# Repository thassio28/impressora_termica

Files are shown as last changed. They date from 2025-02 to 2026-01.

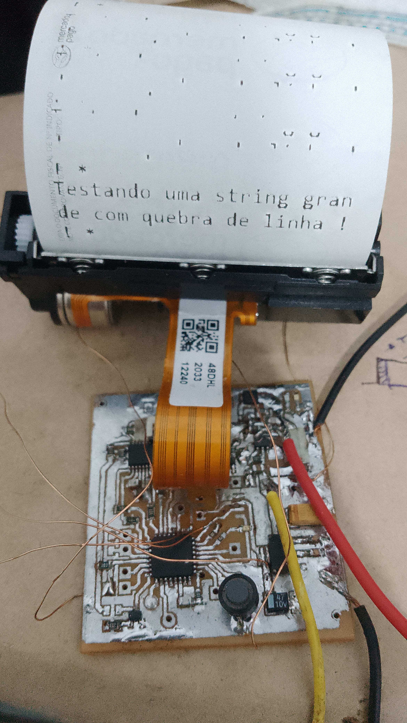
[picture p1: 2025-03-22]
IMG_20240728_152725_571 (1).jpg

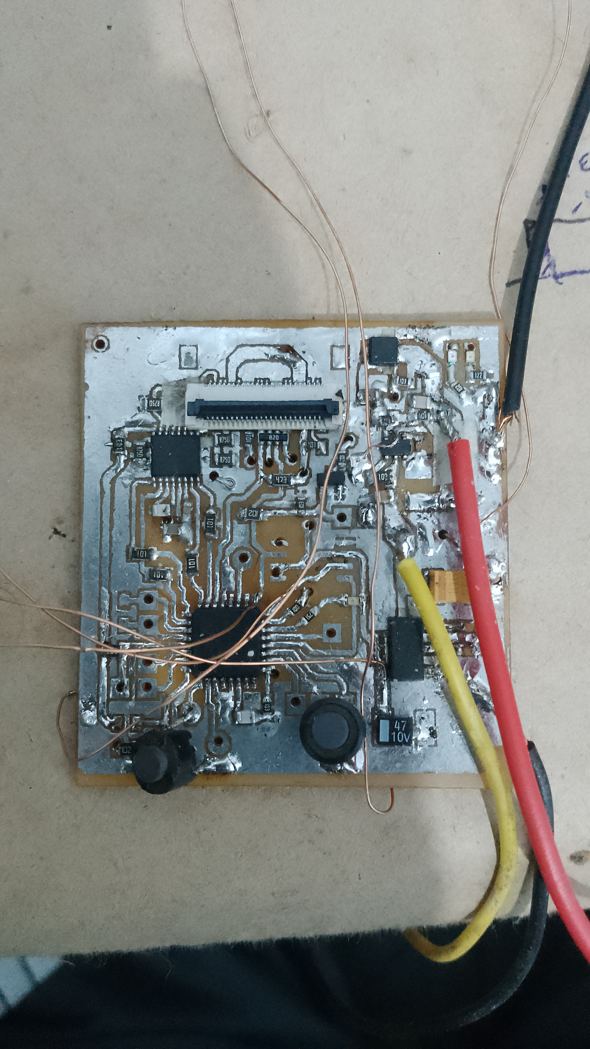
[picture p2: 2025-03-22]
IMG_20240727_220041_866.jpg

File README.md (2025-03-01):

# impressora_termica
Impressora térmica  com atmega328p e cabeça térmica LTP02-245.

Para fazer uma impressão deve ser enviado o texto por meio da porta serial com o comando CR (13) ao final da frase, ao apertar o botão o texto é impresso e é retornado pela serial o texto recebido.

Tensão comunicação 3,3V
BAUD = 9600
Tensão máxima da cabeça térmica (VP) 8V.
Clock interno 8 Mhz

Código e esquema ainda em fase de desenvolvimento.

Versão 1

Video impresão de texto: https://youtube.com/shorts/1QFV2fXhjIA?feature=share

Atualização futura, impressão de imagem: https://youtube.com/shorts/7ARQ239Vu7w?feature=share

Versão 2
Atualização futura 2, talvez display OLED.

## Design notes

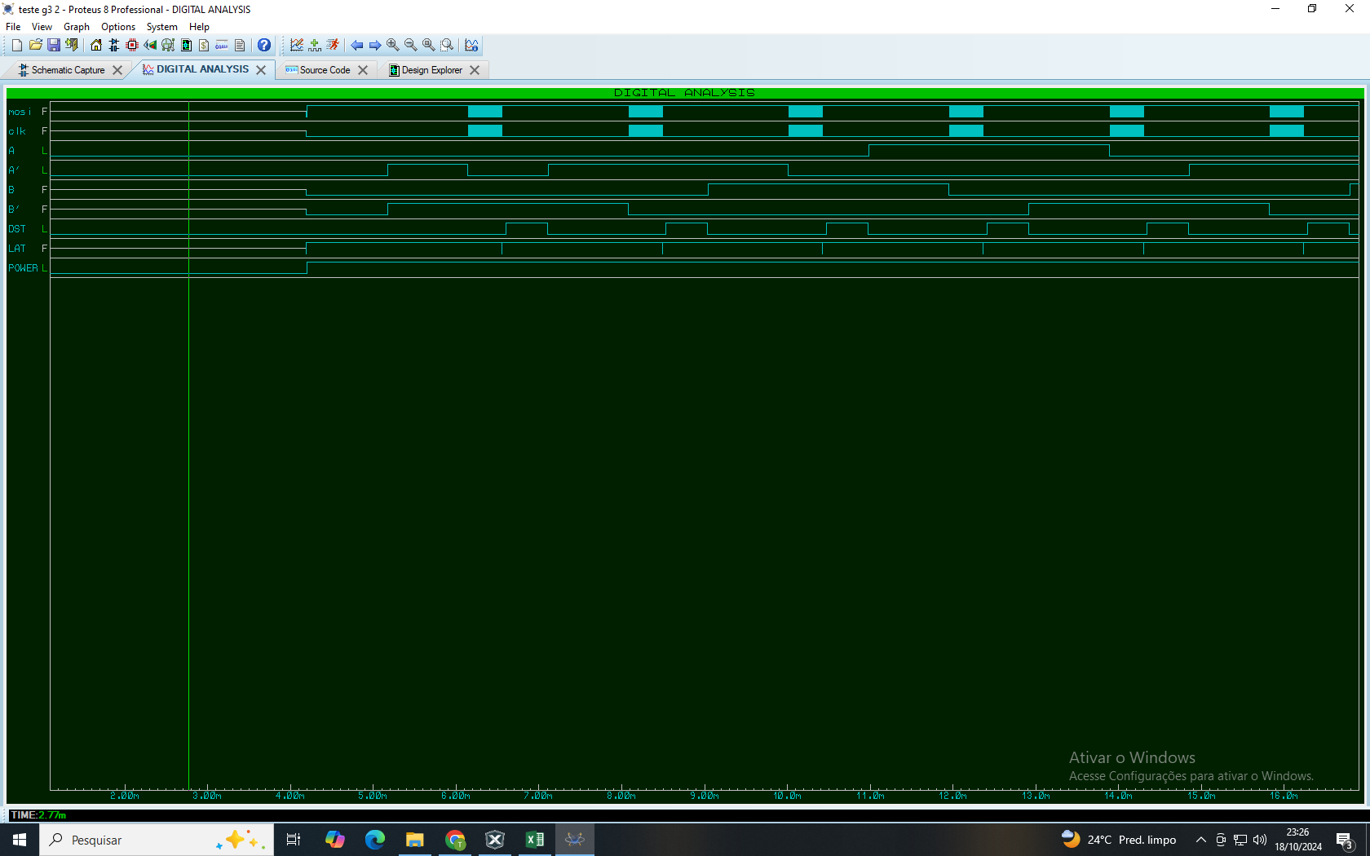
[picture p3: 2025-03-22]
Captura de Tela (138).png

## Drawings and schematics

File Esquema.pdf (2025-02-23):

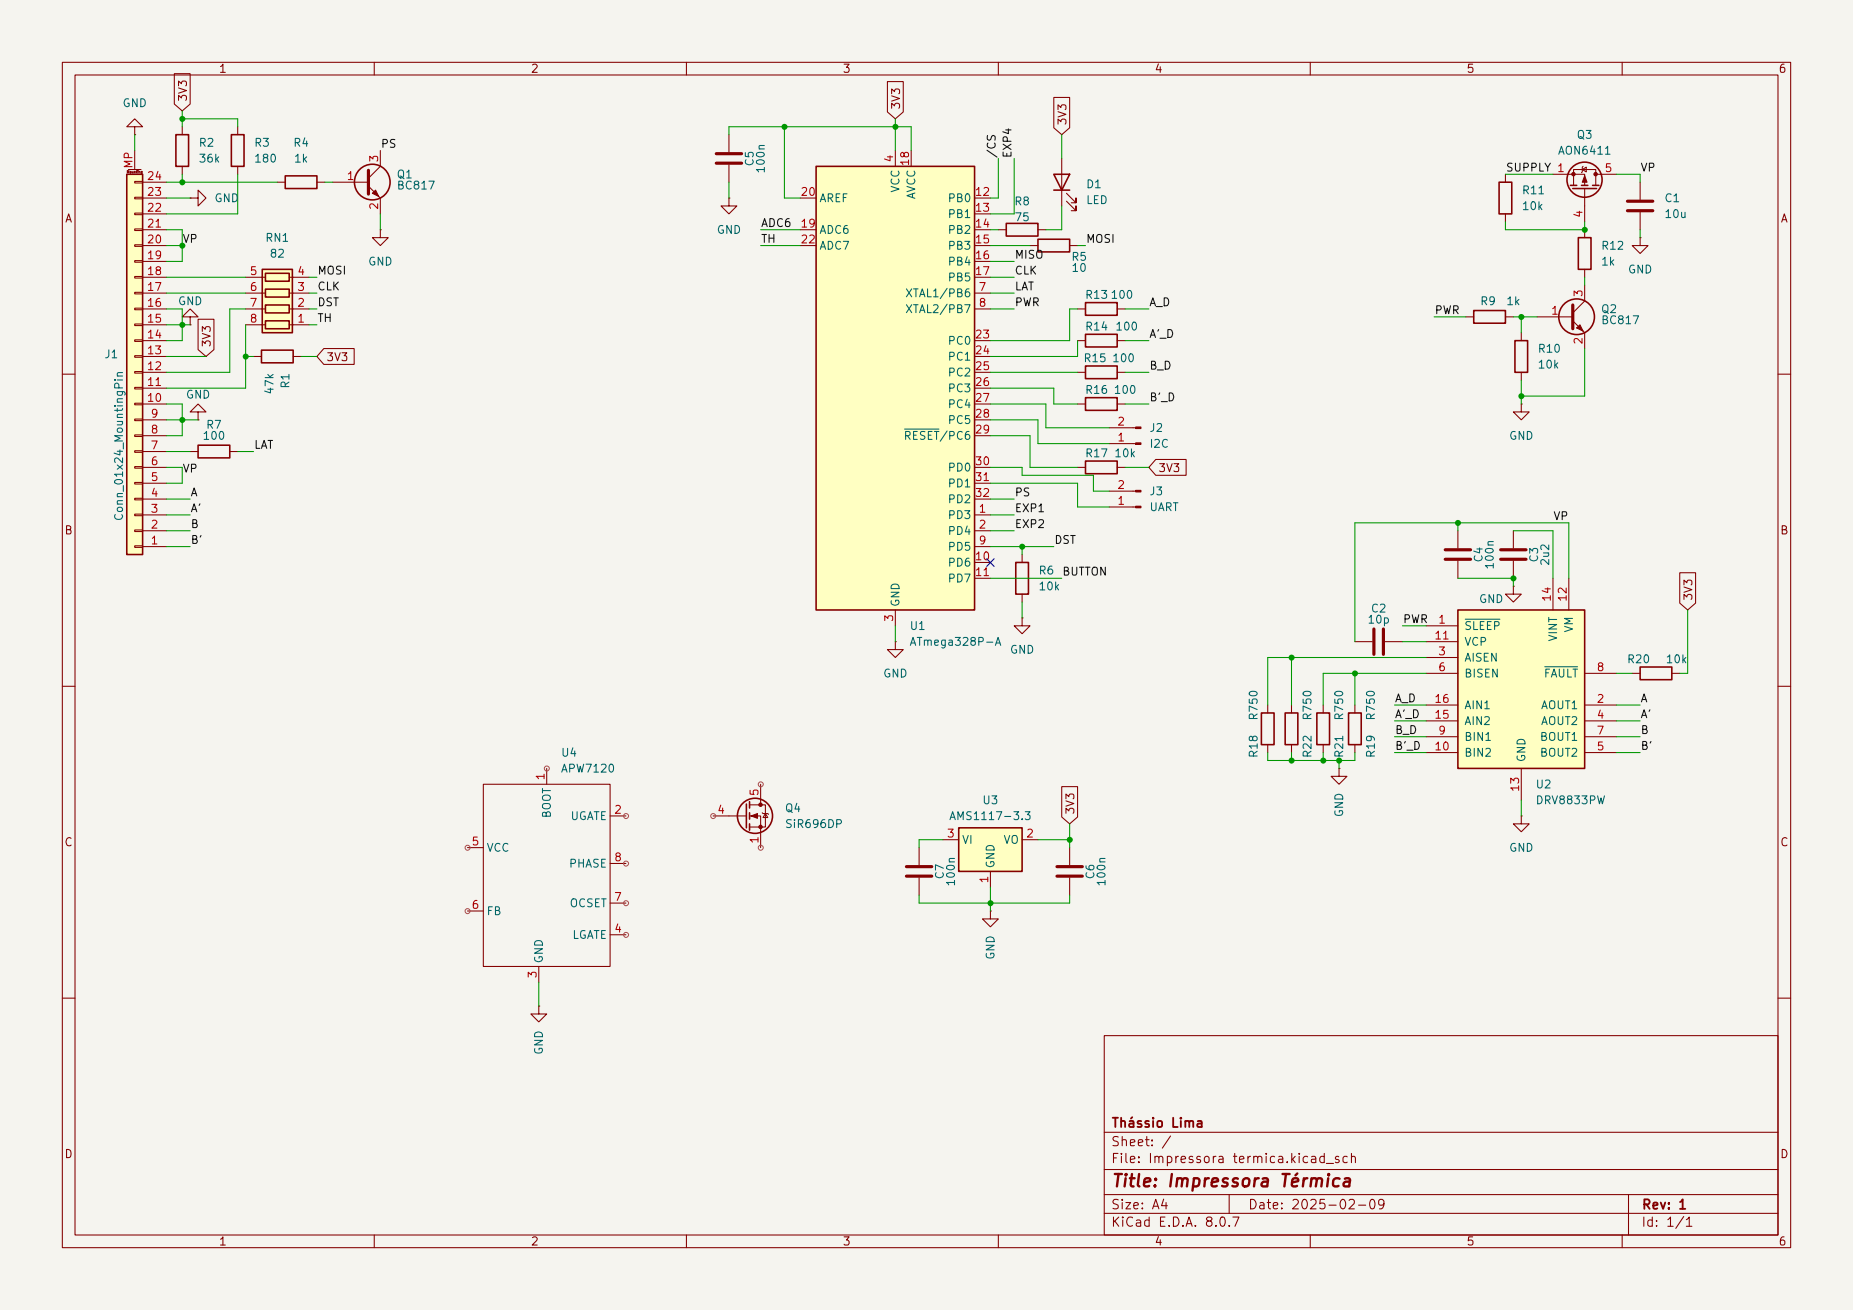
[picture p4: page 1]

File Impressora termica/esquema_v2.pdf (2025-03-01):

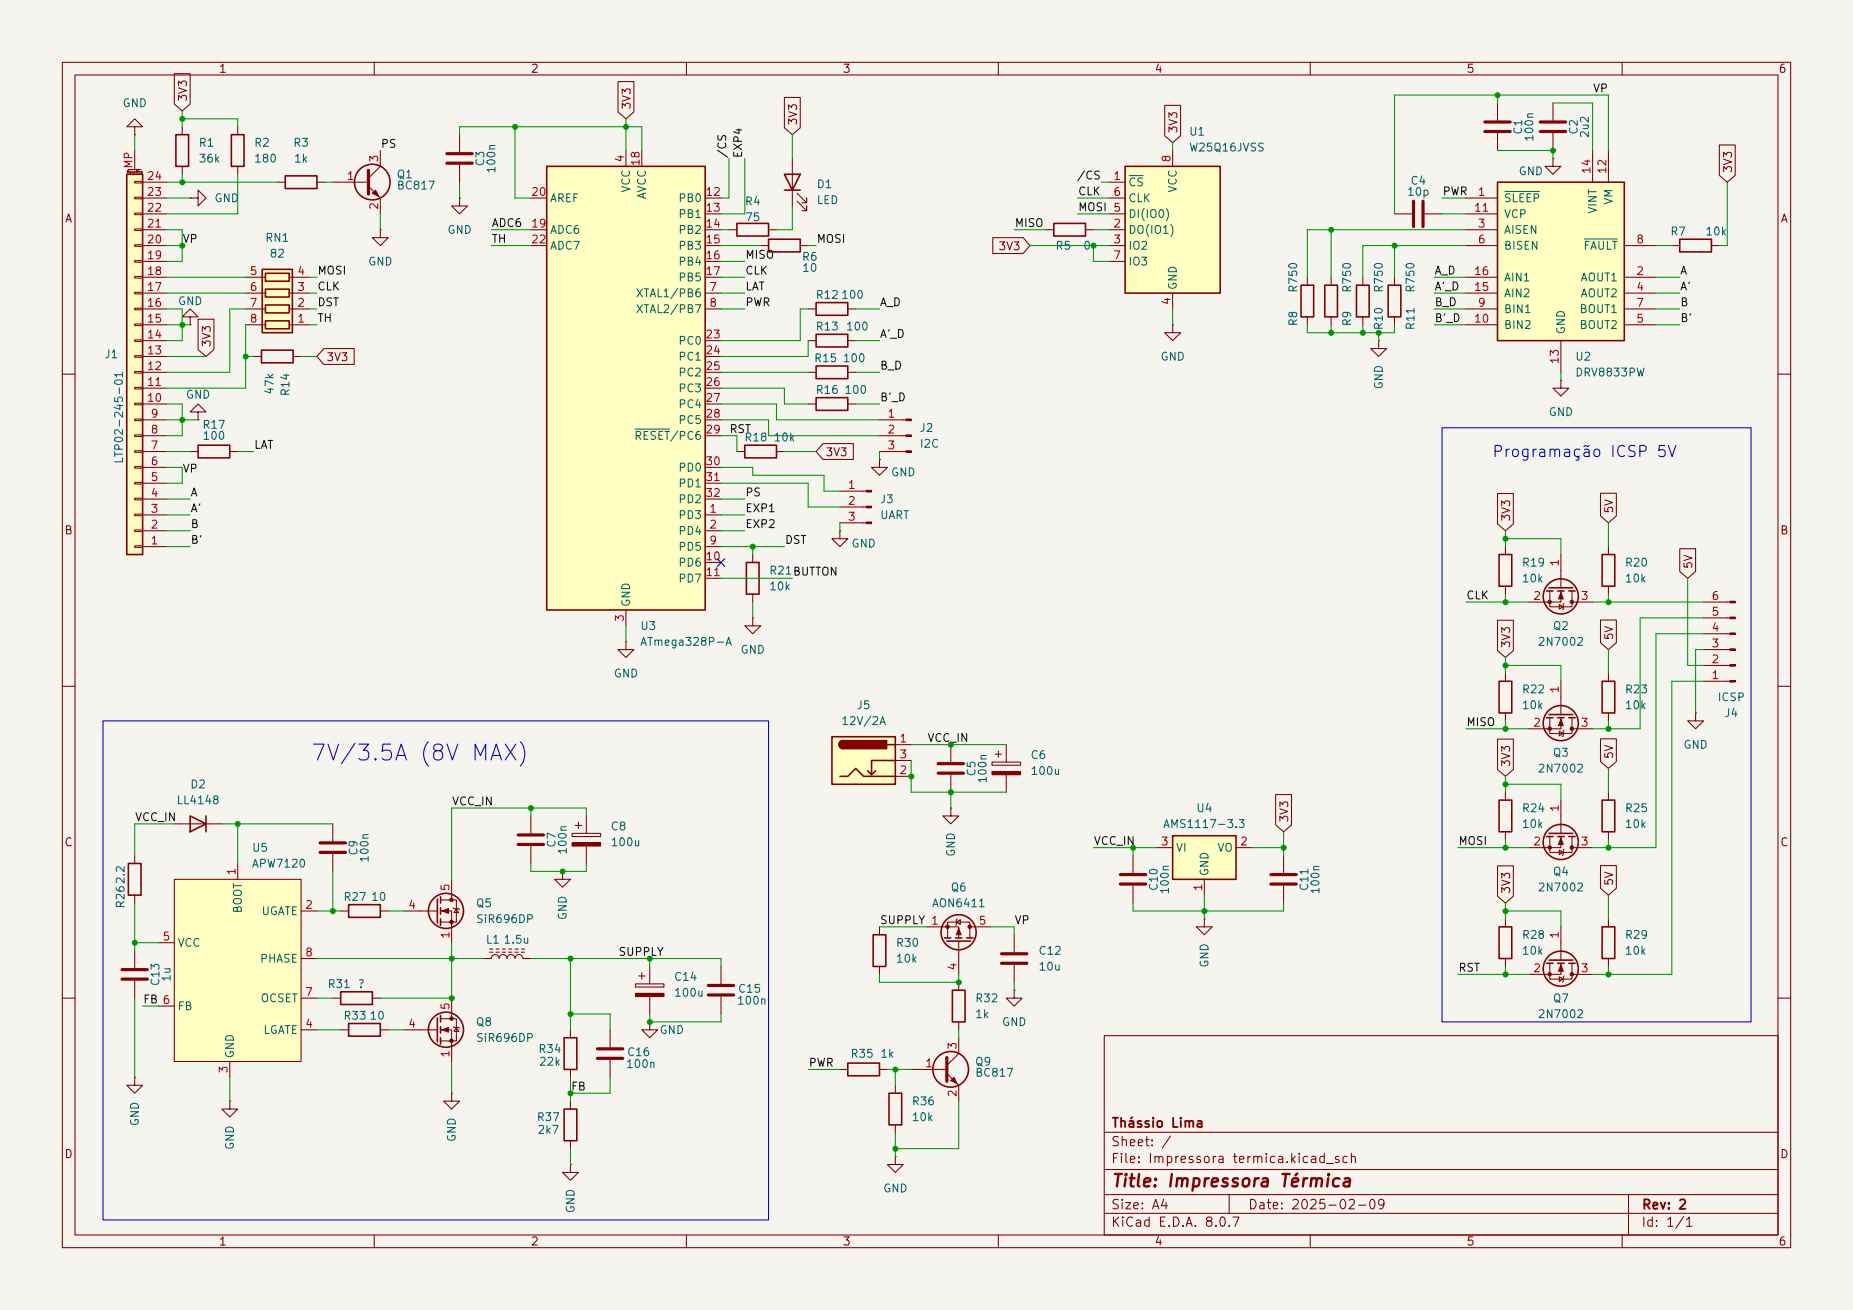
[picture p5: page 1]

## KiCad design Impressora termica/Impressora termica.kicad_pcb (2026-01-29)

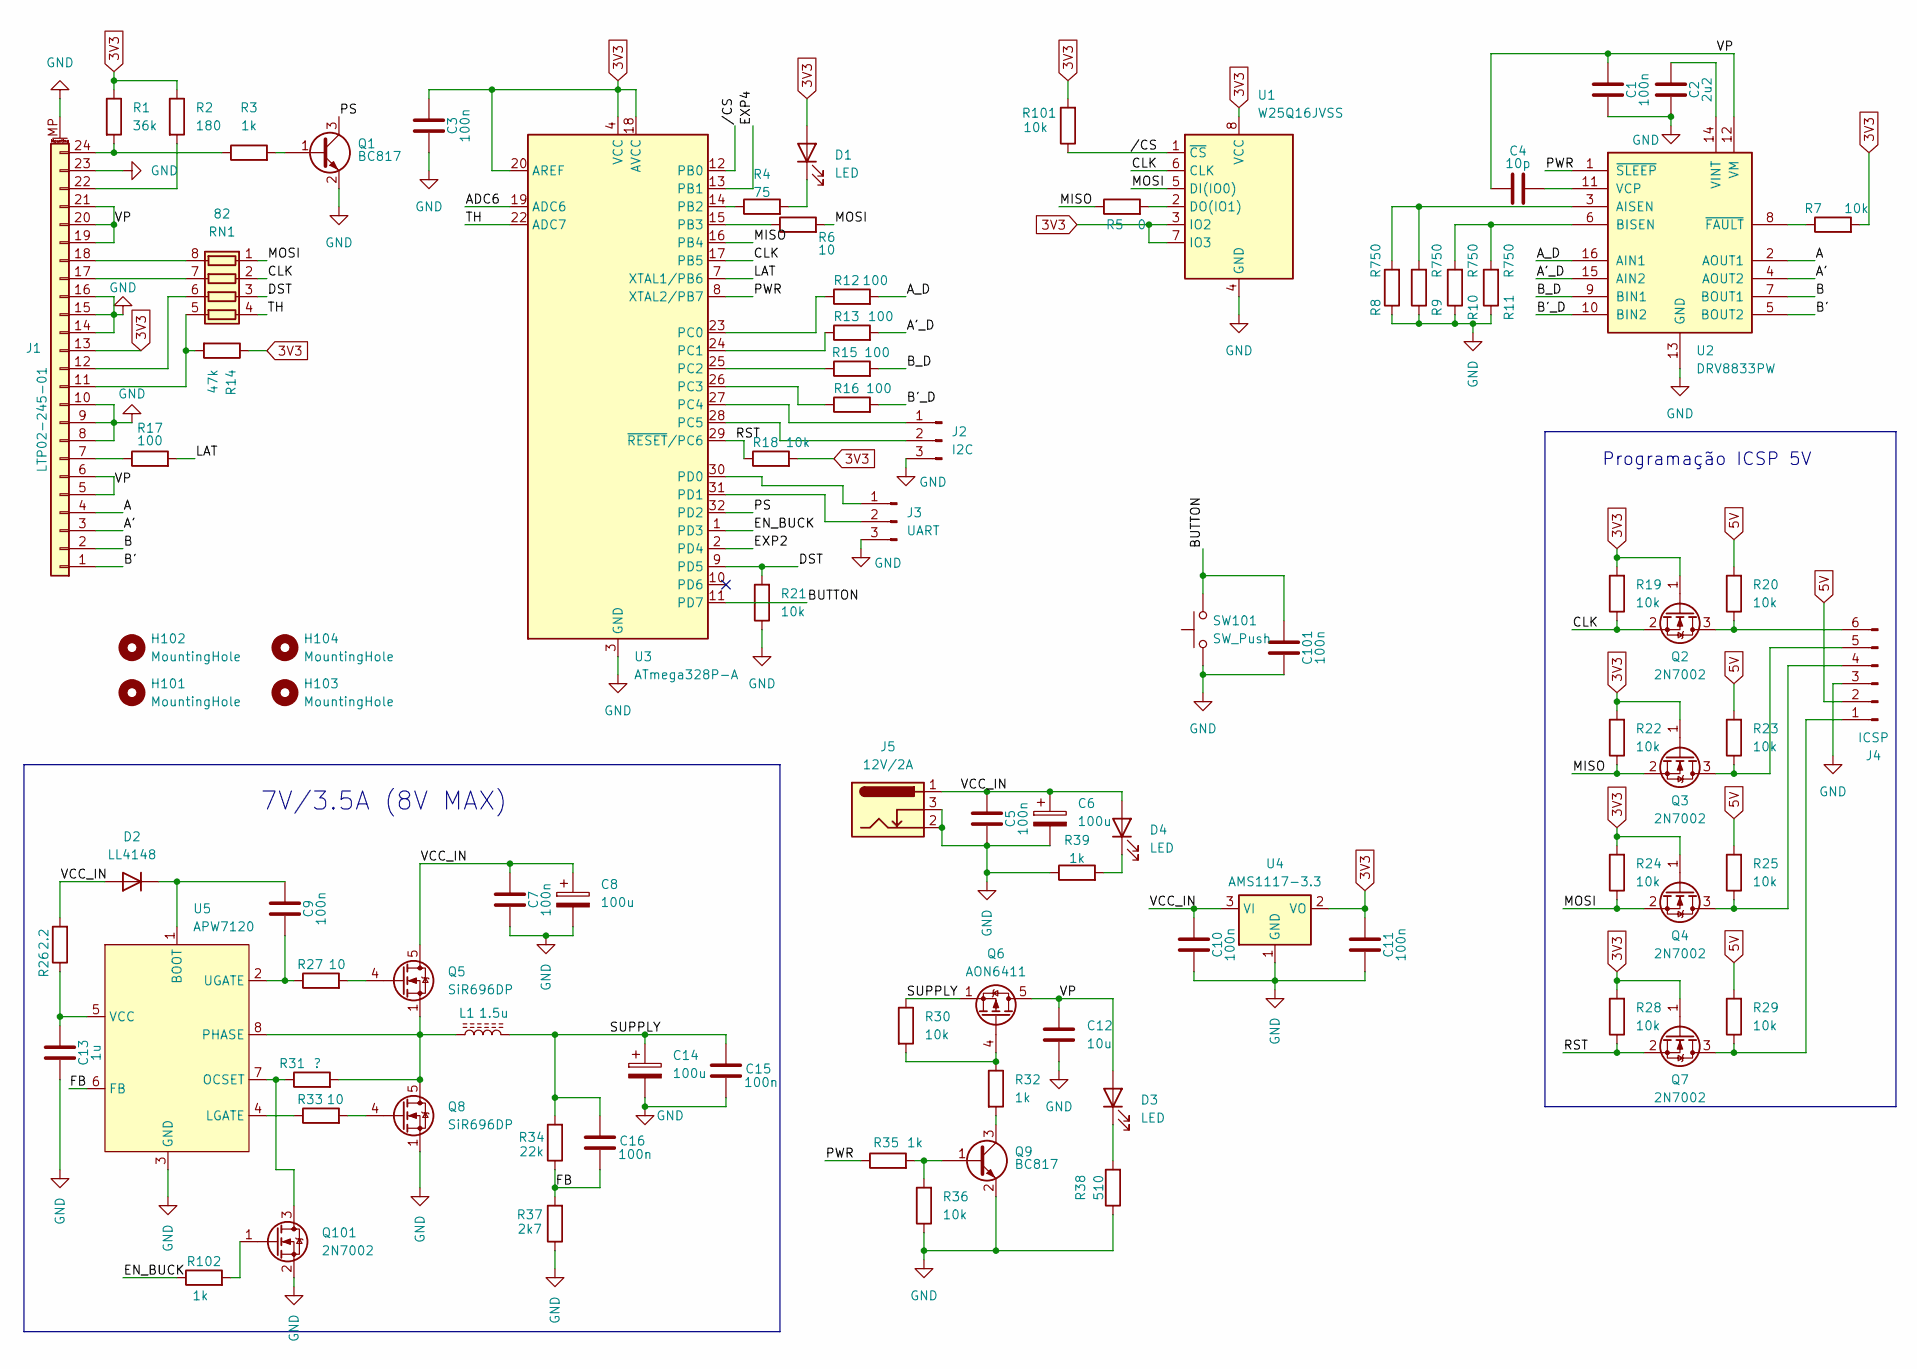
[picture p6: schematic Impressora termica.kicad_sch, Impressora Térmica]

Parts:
C1, C3, C5, C7, C9, C10, C11, C15, C16, C101: 100n; C_0805_2012Metric
C2: 2u2; C_0805_2012Metric
C4: 10p; C_0805_2012Metric
C6: 100u; CP_Elec_6.3x4.5
C8, C14: 100u; CP_Elec_5x4.5
C12: 10u; C_0805_2012Metric
C13: 1u; C_0805_2012Metric
D1, D3, D4: LED; LED_0805_2012Metric
D2: LL4148; D_MiniMELF
H101, H102, H103, H104: MountingHole; MountingHole_3.2mm_M3_DIN965
J1: LTP02-245-01; Hirose_FH12-24S-0.5SH_1x24-1MP_P0.50mm_Horizontal
J2: I2C; PinHeader_1x03_P2.54mm_Vertical
J3: UART; PinHeader_1x03_P2.54mm_Vertical
J4: ICSP; PinHeader_1x06_P2.54mm_Vertical
J5: 12V/2A; BarrelJack_GCT_DCJ200-10-A_Horizontal
L1: 1.5u; L_APV_ANR8040
Q1, Q9: BC817; SOT-23
Q2, Q3, Q4, Q7, Q101: 2N7002; SOT-23
Q5, Q8: SiR696DP; DFN8_3x3_EP_AOS
Q6: AON6411; DFN8_3x3_EP_AOS
R1: 36k; R_0603_1608Metric
R2: 180; R_0603_1608Metric
R3, R35: 1k; R_0805_2012Metric
R4: 75; R_0603_1608Metric
R5: 0; R_0603_1608Metric
R6: 10; R_0805_2012Metric
R7: 10k; R_1206_3216Metric
R8, R9, R10, R11: R750; R_0805_2012Metric
R12, R13, R15, R16: 100; R_0805_2012Metric
R14: 47k; R_0805_2012Metric
R17: 100; R_0603_1608Metric
R18: 10k; R_0805_2012Metric
R19, R20, R21, R22, R23, R24, R25, R28, R29, R30, R36, R101: 10k; R_0603_1608Metric
R26: 2.2; R_0805_2012Metric
R27, R33: 10; R_0603_1608Metric
R31: ?; R_0805_2012Metric
R32, R39, R102: 1k; R_0603_1608Metric
R34: 22k; R_0603_1608Metric
R37: 2k7; R_0603_1608Metric
R38: 510; R_0603_1608Metric
RN1: 82; R_Array_Convex_4x0603
SW101: SW_Push; SW_SPST_CK_RS282G05A3
U1: W25Q16JVSS; SOIC-8_5.23x5.23mm_P1.27mm
U2: DRV8833PW; TSSOP-16_4.4x5mm_P0.65mm
U3: ATmega328P-A; TQFP-32_7x7mm_P0.8mm
U4: AMS1117-3.3; SOT-223-3_TabPin2
U5: APW7120; SOP-8_5.28x5.23mm_P1.27mm

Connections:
3V3: C3.2, C11.2, D1.2 (A), J1.13, Q2.1 (G), Q3.1 (G), Q4.1 (G), Q7.1 (G), R1.1, R2.1, R7.2, R14.1, R18.2, R19.2, R22.2, R24.2, R28.2, R101.2, U1.3 (IO2), U1.7 (IO3), U1.8 (VCC), U3.4 (VCC), U3.6 (VCC), U3.18 (AVCC), U3.20 (AREF), U4.2 (VO)
5V: J4.2, R20.2, R23.2, R25.2, R29.2
/A: J1.4, U2.2 (AOUT1)
/A': J1.3, U2.4 (AOUT2)
/A'_D: R13.2, U2.15 (AIN2)
/ADC6: U3.19 (ADC6)
/A_D: R12.2, U2.16 (AIN1)
/B: J1.2, U2.7 (BOUT1)
/B': J1.1, U2.5 (BOUT2)
/B'_D: R16.2, U2.10 (BIN2)
/BUTTON: C101.2, SW101.2, U3.11 (PD7)
/B_D: R15.2, U2.9 (BIN1)
/CLK: Q2.2 (S), R19.1, RN1.2 (R2.1), U1.6 (CLK), U3.17 (PB5)
/DST: R21.2, RN1.3 (R3.1), U3.9 (PD5)
/EN_BUCK: R102.1, U3.1 (PD3)
/EXP2: U3.2 (PD4)
/EXP4: U3.13 (PB1)
/FB: C16.1, R34.1, R37.2, U5.6 (FB)
/LAT: R17.2, U3.7 (XTAL1/PB6)
/MISO: Q3.2 (S), R5.1, R22.1, U3.16 (PB4)
/MOSI: Q4.2 (S), R6.2, R24.1, RN1.1 (R1.1), U1.5 (DI(IO0))
/PS: Q1.3 (C), U3.32 (PD2)
/PWR: R35.1, U2.1 (~SLEEP), U3.8 (XTAL2/PB7)
/RST: Q7.2 (S), R18.1, R28.1, U3.29 (~RESET/PC6)
/SUPPLY: C14.1, C15.2, C16.2, L1.2, Q6.1 (S), Q6.2 (S), Q6.3 (S), R30.1, R34.2
/TH: RN1.4 (R4.1), U3.22 (ADC7)
/VCC_IN: C5.2, C6.1, C7.2, C8.1, C10.2, D2.2 (A), D4.2 (A), J5.1, Q5.5 (D), R26.2, U4.3 (VI)
/VP: C1.2, C4.1, C12.1, D3.2 (A), J1.5, J1.6, J1.19, J1.20, J1.21, Q6.5 (D), U2.12 (VM)
//CS: R101.1, U1.1 (~CS), U3.12 (PB0)
GND: C1.1, C2.1, C3.1, C5.1, C6.2, C7.1, C8.2, C10.1, C11.1, C12.2, C13.1, C14.2, C15.1, C101.1, J1.8, J1.9, J1.10, J1.14, J1.15, J1.16, J1.23, J1.MP (MountPin), J2.3, J3.3, J4.3, J5.2, J5.3, Q1.2 (E), Q8.1 (S), Q8.2 (S), Q8.3 (S), Q9.2 (E), Q101.2 (S), R8.1, R9.1, R10.1, R11.1, R21.1, R36.1, R37.1, R38.1, R39.1, SW101.1, U1.4 (GND), U2.13 (GND), U3.3 (GND), U3.5 (GND), U3.21 (GND), U4.1 (GND), U5.3 (GND)
unnamed: D1.1 (K), R4.2
unnamed: C9.2, D2.1 (K), U5.1 (BOOT)
unnamed: D3.1 (K), R38.2
unnamed: D4.1 (K), R39.2
unnamed: J1.7, R17.1
unnamed: J1.11, R14.2, RN1.5 (R4.2)
unnamed: J1.12, RN1.6 (R3.2)
unnamed: J1.17, RN1.7 (R2.2)
unnamed: J1.18, RN1.8 (R1.2)
unnamed: J1.22, R2.2
unnamed: J1.24, R1.2, R3.1
unnamed: J2.1, U3.27 (PC4)
unnamed: J2.2, U3.28 (PC5)
unnamed: J3.1, U3.30 (PD0)
unnamed: J3.2, U3.31 (PD1)
unnamed: J4.1, Q7.3 (D), R29.1
unnamed: J4.4, Q4.3 (D), R25.1
unnamed: J4.5, Q3.3 (D), R23.1
unnamed: J4.6, Q2.3 (D), R20.1
unnamed: Q1.1 (B), R3.2
unnamed: Q5.4 (G), R27.2
unnamed: Q6.4 (G), R30.2, R32.1
unnamed: L1.1, Q5.1 (S), Q5.2 (S), Q5.3 (S), Q8.5 (D), R31.2, U5.8 (PHASE)
unnamed: Q8.4 (G), R33.2
unnamed: Q9.1 (B), R35.2, R36.2
unnamed: Q9.3 (C), R32.2
unnamed: Q101.3 (D), R31.1, U5.7 (OCSET)
unnamed: Q101.1 (G), R102.2
unnamed: R5.2, U1.2 (DO(IO1))
unnamed: R8.2, R9.2, U2.3 (AISEN)
unnamed: R10.2, R11.2, U2.6 (BISEN)
unnamed: C4.2, U2.11 (VCP)
unnamed: C2.2, U2.14 (VINT)
unnamed: R7.1, U2.8 (~FAULT)
unnamed: R4.1, U3.14 (PB2)
unnamed: R6.1, U3.15 (PB3)
unnamed: R12.1, U3.23 (PC0)
unnamed: R13.1, U3.24 (PC1)
unnamed: R15.1, U3.25 (PC2)
unnamed: R16.1, U3.26 (PC3)
unnamed: R33.1, U5.4 (LGATE)
unnamed: C9.1, R27.1, U5.2 (UGATE)
unnamed: C13.2, R26.1, U5.5 (VCC)

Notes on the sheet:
7V/3.5A (8V MAX)
Programação ICSP 5V

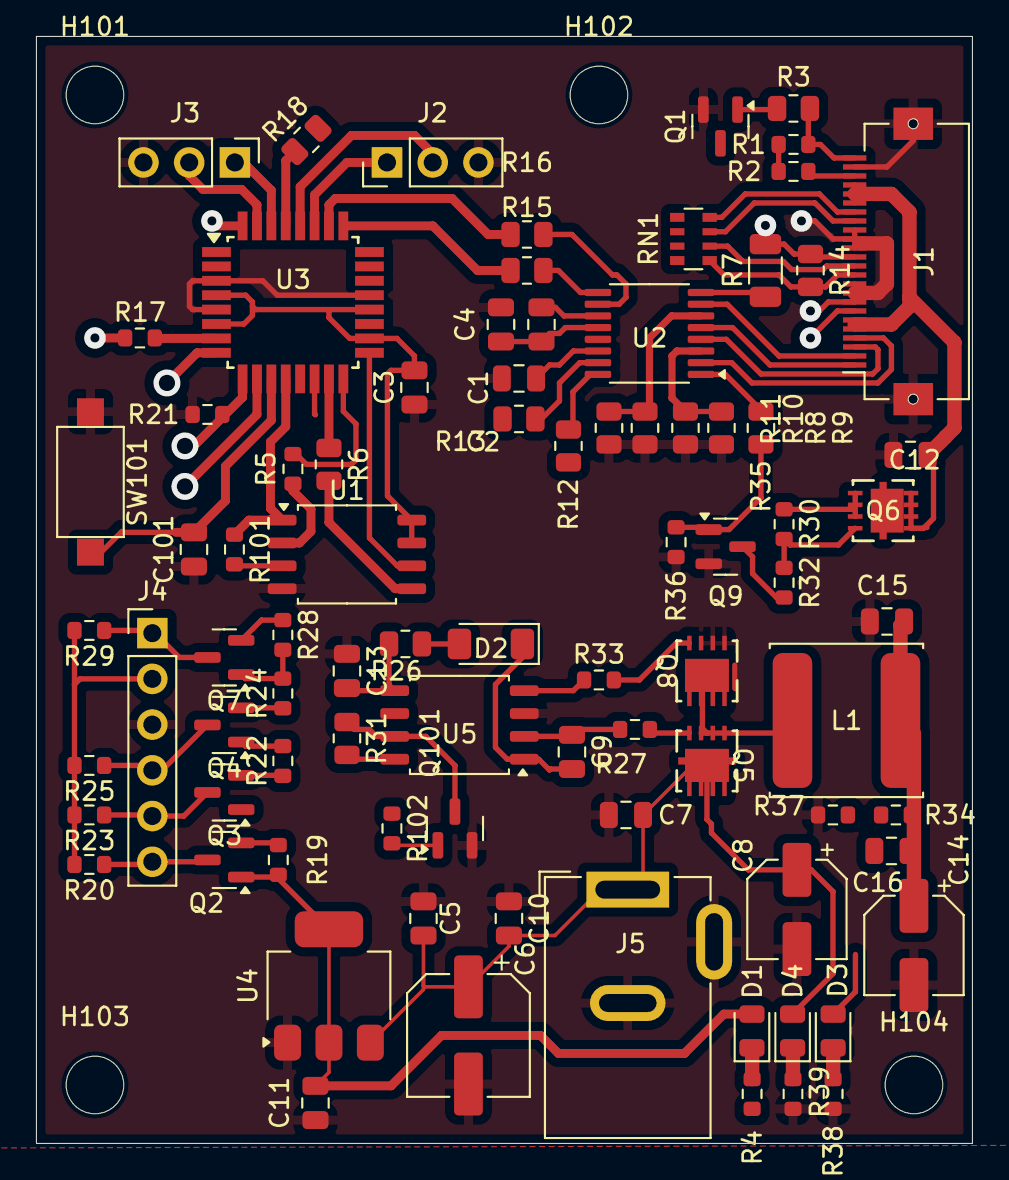
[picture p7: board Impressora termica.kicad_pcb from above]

Board: 2 copper layers, 52.0 x 61.5 mm, 89 parts (0 on the bottom side), 70 nets.

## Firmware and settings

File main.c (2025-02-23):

/* 
 * File:   main.c
 * Author: thassio lima
 *
 * Created on February 9, 2025, 10:07 PM
 */
#define F_CPU 8000000

#include <stdio.h>
#include <stdlib.h>
#include <avr/io.h>
#include <avr/interrupt.h>
#include <util/delay.h>
#include "font.h"
#include <string.h>


void string(void);
void print(void);
void send(void);
void USART_Transmit(void);

volatile uint8_t cont=0; //numero step
volatile uint8_t step[8]= {0b00001010,0b00000010,0b00000110,0b00000100,0b00000101,0b00000001,0b00001001,0b00001000};
volatile uint16_t i=0;    
    /*
                 0b00001000,
				 0b00001001,
				 0b00000001,
				 0b00000101,
				 0b00000100,
				 0b00000110,
				 0b00000010,
				 0b00001010};*/
 char buffer[500];// = "!Frase de teste com quebra de linha";
 char frase[100];

uint16_t tam=0; //tamanho da string
uint8_t linhas;
uint8_t li=0;
uint8_t pos=0;
uint8_t linha=0;
uint8_t lat=0; //verificar quantidade de lat

  uint16_t offset;
uint8_t L=0; //linha matriz caracter
uint8_t n_lat=0;


ISR(TIMER0_OVF_vect){
//PORTB ^=(1<<PB2);//desligar led

PORTC = step[cont];

TCCR0A ^=(1<<COM0B0) | (1<<COM0B1); //ativar desativar OCRB


//percorrer vetor do step
cont++;
n_lat++;
if(n_lat==4){ //enviar a cada 2 lat
    send();
    n_lat=0;
}
if(cont==8) //zerar vetor step
   cont=0;


  
//TCCR0B ^= 0b00000011; //desativar timer
 
 }//end timer0
 
// ISR(SPI_STC_vect){}


ISR(INT0_vect){
PORTB &=~(1<<PB7);//desligar alimentação motor/resistencia
PORTB |=(1<<PB2);//desligar led

//TCCR0B = 0; // desativar timer
TCCR0B &=~(1<<CS00);
TCCR0B &=~(1<<CS01);


}


ISR(ADC_vect){
   
    if(ADCH<25){ //temperatura maior que 75ºC
     PORTB &=~(1<<PB7);//desligar alimentação motor/resistencia
     PORTB |=(1<<PB2);//desligar led
  //   TCCR0B = 0; //desativa timer
   TCCR0B &=~(1<<CS00);
   TCCR0B &=~(1<<CS01);

    }
}

ISR(USART_RX_vect){
    
    buffer[i] = UDR0;
    
    if(buffer[i] == 13) //carriage feed
    {
       // print();
        tam = i;//memcpy(frase,frase,i);
        i=0;
   
    }
    else{
       i++;
    } 
     

}



int main() {

   


//PORTAS
    
DDRB = 0xff;
DDRC = 0b00001111;
PORTC = 0;

DDRD |=(1<<DDD6);//ocr0a /nao usar
DDRD |= (1<<DDD5);//porta resistencia
DDRD &=~(1<<DDD2); //porta sensor
DDRD &= ~(1<<DDD7);//porta botão
DDRD &=~(1<<DDD4);//teste

PORTD &=~(1<<PD6);//ocr0a /nao usar
PORTD |=(1<<PD2); //pull up sensor
PORTD &=~(1<<PD5);//desativar resitencia
PORTD |= (1<<PD7);//pull up botao
PORTB |=(1<<PB6); //porta LAT
PORTD |=(1<<PD4);//teste

//CONFIGURAR SPI
PORTB |=(1<<PB3) | (1<<PB5) |(1<<PB2);
SPCR = (1<<SPE) | (1<<DORD) |  (1<<MSTR);// | (1<<SPIE);
SPSR = (1<<SPI2X);

//CONFIGURAR UART
UBRR0 = 51;//9600
UCSR0A = 0;
UCSR0B = (1<<RXCIE0) | (1<<RXEN0) | (1<<TXEN0);
UCSR0C = (1<<UCSZ01) | (1<<UCSZ00);
//CONFIGURAR INTERRUPCAO

EICRA = 0;// level baixo (1<<ISC01); //borda de descida gera interrupcao int0
EIMSK = (1<<INT0); //pino 32

//CONFIGURAR ADC

ADMUX = (1<<REFS0) | (1<<MUX0) | (1<<MUX1) | (1<<MUX2) | (1<<ADLAR);
ADCSRA = (1<<ADEN) | (1<<ADSC) | (1<<ADATE) | (1<<ADPS0) | (1<<ADPS1) | (1<<ADPS2)| (1<<ADIE);
ADCSRB = (1<<ADTS2);//Timer/Counter0 overflow


//CONGIFURAR TIMER
TCCR0A = 0;
TCCR0B = 0;

OCR0A = 115;//frequencia ->+
OCR0B = 70;//duty
TCCR0A = (1<<COM0B0) | (1<<COM0B1) | (1<<WGM00) | (1<<WGM01); // setar pino DST pulso, modo invertido setar comparação limpar do topo
TCCR0B = (1<<CS00)| (1<<CS01) | (1<<WGM02); //clock/64

TIMSK0 = (1<<TOIE0);

TCCR0B ^= 0b00000011; //desativar timer
sei();

   
//print();
//PORTC = 0b00001010; //step inicial do motor
   
   
   
            //TCCR0B ^= 0b00000011;
//print();
   
   
  while(1){
        if(!(PIND &(1<<PD7))){
            while(!(PIND &(1<<PD7)));
                     //PORTB ^=(1<<PB2);// desliga led   
            USART_Transmit();
         print();  
         //USART_Transmit();
        }
        /*
        else if(!(PIND &(1<<PD4))){
            while(!(PIND &(1<<PD4)));
                     PORTB ^=(1<<PB2);// desliga led 
        }
        */
        
     };//end while
   return 0;
 }//end main

void string(void){

  
    linhas = (tam/24)+1;    //quantidade de linhas
    
    while(tam != linhas*24){
        buffer[tam]= ' ';    //preencher resto da frase com espaço
        tam++;
    }
    buffer[tam] = 13; //CR no ultimo caracter
    
}

void send(void){

   uint8_t data;
  
  if(buffer[pos+linha] == 13){ //desligar/parar ao chegar ao fim
      TCCR0B &=~(1<<CS00);//desligar timer
      TCCR0B &=~(1<<CS01);
      PORTB &=~(1<<PB7); //desligar power
      PORTB |=(1<<PB2);// desliga led
      pos=0, linha=0, offset=0,li=0,L=0,cont=0;//zerar variaveis, posicao inicial
      memset(buffer,13,500); //limpar buffer

  }
    while(pos <24){
        
// bytes_per_char = font_height * (font_width / 8 + ((font_width % 8) ? 1 : 0))
// offset = (ascii_code(character) - ascii_code(' ')) * bytes_per_char
// data = consolas_20pt[offset]
// 
        
        // bytes_per_char = 32*(16/8+((16%8)? 1:0));
         offset = (buffer[pos+linha] - 32) * 64;
         data = pgm_read_byte_near(&font[offset+li+L]);
         li++;//proximo byte
        // letra = pgm_read_byte_near(&font[(((frase[pos+li]-32)*64)+(byte))]); //enviar uma letra
        SPDR = data;
        while(!(SPSR & (1<<SPIF)));  //aguardar o envio
    
        data = pgm_read_byte_near(&font[offset+li+L]);

        //letra = pgm_read_byte_near(&font[(((frase[pos+li]-32)*64)+(byte+1))]); //enviar uma letra
        SPDR = data;
        while(!(SPSR & (1<<SPIF)));
        
        li=0;//zerar posicao do byte
            ++pos; //proximo caracter
           
        }
  
   pos=0;//posicao na string
   L+=2;//linha de texto
  
  
    PORTB ^=(1<<PB6); // LAT gravar dados
    PORTB ^=(1<<PB6);
    if(L>62){ //proxima linha na impressao
    linha+=24;
    L=0;
    }
    
    
}

void print(void){
    PORTB &=~(1<<PB2); //ligar led
    string();//converter frase da memoria
    send();
    PORTB |=(1<<PB7); // Power
    PORTC = 0b00001010; //step inicial do motor
    TCCR0B ^= 0b00000011; //ativar timer
    
}

void USART_Transmit(void)
{
/* Wait for empty transmit buffer */
    while(buffer[i] != 13){
        PORTB &=~(1<<PB2); //ligar led
while (!(UCSR0A & (1<<UDRE0)));
/* Put data into buffer, sends the data */
UDR0 = buffer[i];
i++;
    }
    i=0;
    PORTB |=(1<<PB2); //desligar led
}

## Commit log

2025-02-23 Primeira versão
    Arquivo fonte e .hex, esse código permite o envio de uma frase pela porta serial e ao apertar o botão o texto é impresso.
2025-03-01 Versão 2
    Versão 2 do esquema com conversor buck de maior potência e conversor de nível lógico para programação ICSP.
2026-01-29 Kicad files
    Placa V2 em desenvolvimento.
    [Impressora termica.kicad_pcb, Impressora termica.kicad_sch]
